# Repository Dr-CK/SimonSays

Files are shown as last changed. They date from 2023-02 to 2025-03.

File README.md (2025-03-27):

# SimonSays
 A reimagining of the [Simon](https://en.wikipedia.org/wiki/Simon_(game)) memorization game.
 
 Press the colored buttons in the right order to progress in the game!

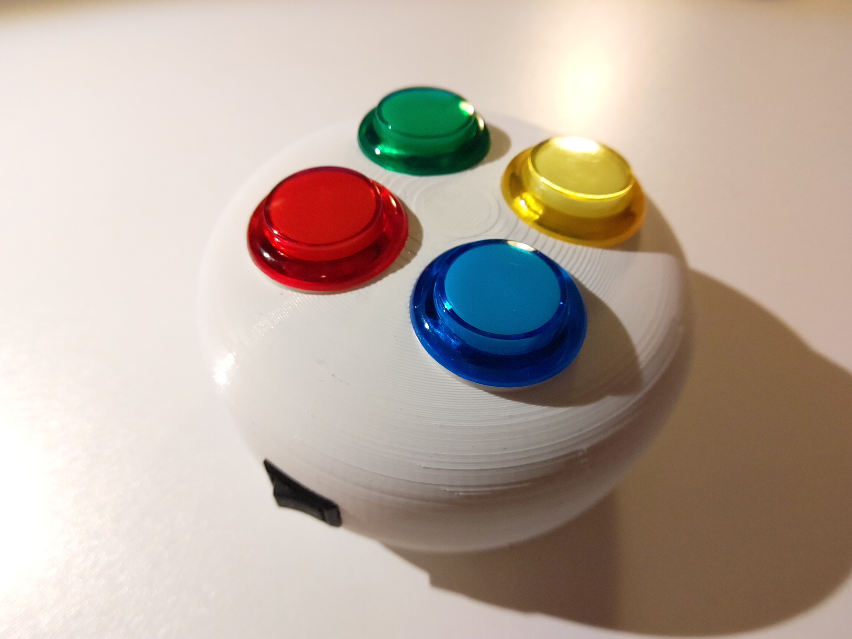
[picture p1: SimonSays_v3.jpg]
Simon Says game

  
 It's controlled by an Arduino and uses standard LED arcade buttons.

 See it in action on [Youtube](https://youtu.be/gggHmTBMl-0)!

## Putting it together

 Follow the instructions below to build your own!

### 3D printed enclosure

 The enclosure is also available on [Printables](https://www.printables.com/model/404689). If you do make your own, consider uploading a Make!

 The enclosure prints in two parts, I printed the bottom part completely without supports, which is not the prettiest on the inside, but it works. For the top part I recommend blocking support structures for the speaker mount and hole, but using supports for the roof and power switch mount.

 I printed mine in white PLA on an Ender 5 Pro (0.4mm nozzle) with 0.2mm layer height, 15% grid infill, and 4 vertical shells.

### Bill of materials
 - Arduino pro mini
 - 4x 24mm LED illuminated arcade buttons
 - Piezo buzzer (12mm diameter) + current limiting resistor
 - Power switch (12x8mm)
 - 9V battery + connector
 - 4x 3mm screws

### Assembly
 1. Upload the supplied code to the Arduino.
 2. Mount the buttons in the following clockwise order: Red - Green - Yellow - Blue
 3. Fit the piezo buzzer in the circular mount.
 4. Mount the power switch in the rectangular hole.
 5. Connect all components according to the schematic.
 6. Attach the 9V battery.
 7. Close the two halves of the enclosure using the four 3mm screws.

## Play time!

 The basics should be fairly intuitive, but here are some details about how it works: The goal is to repeat the displayed sequence for as long as possible.
 There's no explicit way to see the current sequence length, but there will be a little melody playing after finishing 8, 16, 24, etc... steps.
 It will also play another melody when setting a new high score. 

### Hold down buttons during power-up to set the game mode
 - Green: Easy mode (three attempts instead of just one) - Easy mode has it's own high score
 - Red: Reverse mode (enter the sequence in reverse order)
 - Blue: Multiplayer mode (see below)
 - Yellow: Silent mode (No sound)
 - All buttons: Free play
 - Hold down all buttons until all lights are out to reset the highscore
 - (Buttons can be pressed in combination)
   
### Multiplayer mode
 1. Unlimited number of players
 2. A simple animation is shown before the game starts
 3. Player 1 picks the first color
 4. Player 2 presses the same color and then choses the next color
 5. Every player in turn has to input the correct sequence as usual, and finally chose the next color in the sequence
 6. Press the wrong color and you are out!
 7. Last player standing wins!
 
### Screen saver

 After a while of inactivity, it will start flashing the buttons just for fun. To get back to the game, hold down any button during the change between animation sequences.
 
 Wait a bit longer and there will be another surprise :)

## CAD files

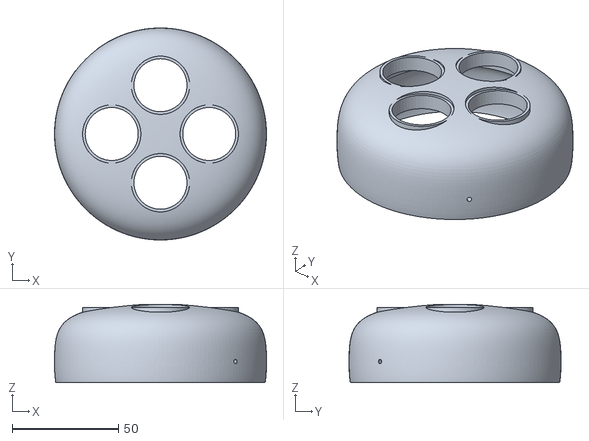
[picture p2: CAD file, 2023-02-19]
Case/Simon Says Top.stl
100.0 x 100.0 x 37.0

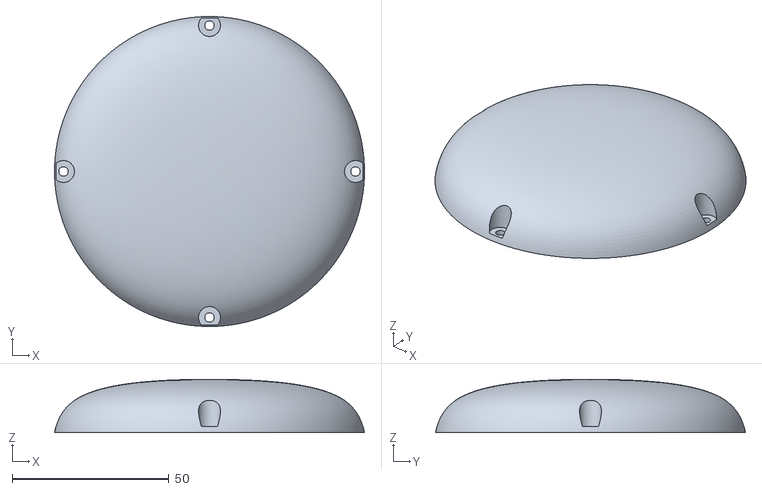
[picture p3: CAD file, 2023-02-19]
Case/Simon Says Bottom.stl
98.7 x 98.7 x 17.0

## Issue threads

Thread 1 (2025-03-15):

Resistor question

PhilipKyleBoone, 2025-03-15:
Thanks for making this project!

Which resistors should be used fopr the LED's?

Take Care
Philip

Dr-CK, 2025-03-17:
Thank you for your interest!
The proper resistor value will depend on which LEDs you choose and how
bright you want them to be.
I used push switches with built-in LEDs and already equipped with current
limiting resistors. So in that case there's no need for additional
resistors.

On Sat, 15 Mar 2025, 14:54 PhilipKyleBoone, ***@***.***>
wrote:

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

PhilipKyleBoone, 2025-03-27:
Hey Christoffer,

no worries I will no doubt find a use for the 28mm buttons. The worst part was having to wait for the 24mm buttons to arrive.

I made some modifications to the bottom half. Will be posting it as a remix on printables and thingyverse

Thanks again for this excellent design!
Cheers
Philip

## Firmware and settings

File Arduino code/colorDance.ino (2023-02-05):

/*
 * SIMON SAYS - COLOR DANCE
 * Christoffer Karlsson 2019
 * 
 * Some functions to do entertaining "color dance" animations
 * on the Simon Says display, kinda like a screen saver.
 * Press any button between animations to return to the game.
 * Leave the animations on for a while for another surprise...
 */

//Perform color dance animations
void performColorDance() {
  //Serial.println("Starting color dance...");

  //Do 15 separate animations
  for (int i=0; i<15; i++){
    switch (random(5)) { //Randomize each time
      case 0: dance0(); break;
      case 1: dance1(); break;
      case 2: dance2(); break;
      case 3: dance3(); break;
      case 4: dance4(); break;
    }
    delay(1000);

    //If any button is pressed, return to the game
    for (int i=0; i<4; i++)
      if (digitalRead(buttonPin[i]) == LOW)
        return;
  }

  //When animations are finished, play the Super Mario theme :)
  if (soundOn) playSuperMarioTheme();

  while (true) {} //Then do nothing
}

//Dance 0: Simple spin
void dance0() {
  //Serial.println("Simple spin");
  for (int j=0; j<16; j++)
    for (int i=0; i<4; i++) {
      digitalWrite(ledPin[i], HIGH);
      delay(100);
      digitalWrite(ledPin[i], LOW);
    }
}

//Dance 1: Fade all colors in and out
void dance1() {
  //Serial.println("All fade");
  int change = 5;
  for (int k=0; k<8; k++) {
    for (int j=0; j<256; j+=change) {
      for (int i=0; i<4; i++) analogWrite(ledPin[i], j);
      delay(20);
    }
    for (int j=255; j>=0; j-=change) {
      for (int i=0; i<4; i++) analogWrite(ledPin[i], j);
      delay(20);
    }
  }
  for (int i=0; i<4; i++) digitalWrite(ledPin[i], LOW);
}

//Dance 2: Spin around fading the colors
void dance2() {
  //Serial.println("Fade spin");
  int change = 8;
  for (int k=0; k<8; k++) {
    for (int i=0; i<4; i++) {
      for (int j=0; j<256; j+=change) {
        analogWrite(ledPin[i], 255-j);
        analogWrite(ledPin[(i+1)%4], j);
        delay(20);
      }
      digitalWrite(ledPin[i], LOW);
    }
  }
  for (int i=0; i<4; i++) digitalWrite(ledPin[i], LOW);
}

//Dance 3: Light up colors pairwise
void dance3() {
  //Serial.println("Cross");
  for (int j=0; j<16; j++)
    for (int i=0; i<2; i++) {
      digitalWrite(ledPin[i], HIGH);
      digitalWrite(ledPin[i+2], HIGH);
      delay(200);
      digitalWrite(ledPin[i], LOW);
      digitalWrite(ledPin[i+2], LOW);
    }
}

//Dance 4: Speeding up random colors
void dance4() {
  //Serial.println("R2D2");
  int color; // = -1;
  for (float d = 500.0f; d > 15.0f; d *= 0.94f) {
    color = getNewRandomColor(color);
    digitalWrite(ledPin[color], HIGH);
    delay(int(d));
    digitalWrite(ledPin[color], LOW);
  }
}

//Dance 5: Another fading color spin
/*void dance5() {
  int change = 8;
  for (int k=0; k<8; k++) {
      for (int j=0; j<256; j+=change) {
        analogWrite(ledPin[0], j);
        delay(10);
      }
      for (int j=0; j<256; j+=change) {
        analogWrite(ledPin[0], 255-j);
        analogWrite(ledPin[1], j);
        analogWrite(ledPin[3], j);
        delay(10);
      }
      for (int j=0; j<256; j+=change) {
        analogWrite(ledPin[1], 255-j);
        analogWrite(ledPin[3], 255-j);
        analogWrite(ledPin[2], j);
        delay(10);
      }
      for (int j=0; j<256; j+=change) {
        analogWrite(ledPin[2], 255-j);
        delay(10);
      }
    }
}*/

//Return a random color which is not the same as the old color
int getNewRandomColor(int oldColor) {
  int color;
  do color = random(4);
  while (color == oldColor);
  return color;
}

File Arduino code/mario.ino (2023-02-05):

/*
 * SIMON SAYS - SUPER MARIO THEME SONG
 * Christoffer Karlsson 2019
 * 
 * Plays the Super Mario theme song on the Simon Says game
 */

const int marioNoteLength = 50,
  marioN = 140, marioNReprises = 9,
  marioNotes[marioN] = {NOTE_E5, NOTE_E5, NOTE_E5, NOTE_C5, NOTE_E5, NOTE_G5, NOTE_G4, NOTE_C5, NOTE_G4, NOTE_E4, NOTE_A4, NOTE_B4, NOTE_AS4, NOTE_A4, NOTE_G4, NOTE_E5, NOTE_G5, NOTE_A5, NOTE_F5, NOTE_G5, NOTE_E5, NOTE_C5, NOTE_D5, NOTE_B4, NOTE_C3, NOTE_G5, NOTE_FS5, NOTE_F5, NOTE_DS5, NOTE_E5, NOTE_GS4, NOTE_A4, NOTE_C5, NOTE_A4, NOTE_C5, NOTE_D5, NOTE_C3, NOTE_G5, NOTE_FS5, NOTE_F5, NOTE_DS5, NOTE_E5, NOTE_C6, NOTE_C6, NOTE_C6, NOTE_G3, NOTE_C3, NOTE_G5, NOTE_FS5, NOTE_F5, NOTE_DS5, NOTE_E5, NOTE_GS4, NOTE_A4, NOTE_C5, NOTE_A4, NOTE_C5, NOTE_D5, NOTE_C3, NOTE_DS5, NOTE_D5, NOTE_C5, NOTE_G3, NOTE_G3, NOTE_C3, NOTE_C5, NOTE_C5, NOTE_C5, NOTE_C5, NOTE_D5, NOTE_E5, NOTE_C5, NOTE_A4, NOTE_G4, NOTE_C5, NOTE_C5, NOTE_C5, NOTE_C5, NOTE_D5, NOTE_E5, NOTE_G3, NOTE_C3, NOTE_G2, NOTE_C5, NOTE_C5, NOTE_C5, NOTE_C5, NOTE_D5, NOTE_E5, NOTE_C5, NOTE_A4, NOTE_G4, NOTE_E5, NOTE_C5, NOTE_G4, NOTE_GS4, NOTE_A4, NOTE_F5, NOTE_F5, NOTE_A4, NOTE_B4, NOTE_A5, NOTE_A5, NOTE_A5, NOTE_G5, NOTE_F5, NOTE_E5, NOTE_C5, NOTE_A4, NOTE_G4, NOTE_E5, NOTE_C5, NOTE_G4, NOTE_GS4, NOTE_A4, NOTE_F5, NOTE_F5, NOTE_A4, NOTE_B4, NOTE_F5, NOTE_F5, NOTE_F5, NOTE_E5, NOTE_D5, NOTE_C5, NOTE_E4, NOTE_E4, NOTE_C4, NOTE_C5, NOTE_G4, NOTE_E4, NOTE_A4, NOTE_B4, NOTE_A4, NOTE_GS4, NOTE_AS4, NOTE_GS4, NOTE_G4, NOTE_E4, NOTE_G4},
  marioLengths[marioN] = {150,   300,     300,     150,     300,     600,     600,     450,     450,     450,     300,     300,     150,      300,     200,     200,     200,     300,     150,     300,     300,     150,     150,     450,     300,     150,     150,      150,     300,      300,     150,      150,     300,     150,     150,     150,     300,     150,     150,      150,     300,      300,     300,     150,     300,     300,     300,     150,     150,      150,     300,      300,     150,      150,     300,     150,     150,     150,     300,     450,      450,     450,     150,     300,     300,     150,     300,     300,     150,     300,     150,     300,     150,     600,     150,     300,     300,     150,     150,     150,     450,     450,     300,     150,     300,     300,     150,     300,     150,     300,     150,     600,     150,     300,     450,     300,      150,     300,     150,     600,     200,     200,     200,     200,     200,     200,     150,     300,     150,     600,     150,     300,     450,     300,      150,     300,     150,     600,     150,     300,     150,     200,     200,     200,     150,     300,     150,     600,     500,     500,     500,     200,     200,     200,     220,      220,      220,      240,     240,     240},
  marioReprises[marioNReprises] = {24, 65, 92, 24, 24, 128, 128, 92, 7},
  marioGoTo[marioNReprises] =     {7,  24, 0,  7,  92, 92,  65,  0,  92};

void playSuperMarioTheme() {
  //Serial.println("Playing Super Mario Theme...");
  int color = -1, repr = 0;
  for (int i=0; i<marioN; i++) {
    if (repr < marioNReprises && i == marioReprises[repr])
      i = marioGoTo[repr++];
    color = getNewRandomColor(color);
    digitalWrite(ledPin[color], HIGH);
    tone(soundPin, marioNotes[i], marioNoteLength);
    delay(marioLengths[i]);
    digitalWrite(ledPin[color], LOW);
  }
}

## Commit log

2023-02-05 Arduino code
2023-02-05 3D printed case
    Prusaslicer 3mf files project for Ender 5 with some support and variable height settings
    [Simon Says Shell v11 Lower.3mf, Simon Says Shell v11 Lower.stl, Simon Says Shell v11 Upper.3mf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]
2023-02-19 Updated stl files
    [Simon Says Bottom.stl, Simon Says Shell v11 Lower.3mf, Simon Says Shell v11 Lower.stl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]
